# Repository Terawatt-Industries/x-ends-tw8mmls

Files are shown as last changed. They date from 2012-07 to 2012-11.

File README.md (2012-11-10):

#RepRap X-Ends for Terawatt Industries Leadscrew/Nut and LM8UU Bearings or Acetal Bushings
-----------------------------------------------------------------------------------------

This is a modified version of the popular prusa/mendelmax x-ends for use with acetal bushings from SDP and Terawatt Industries leadscrew/nut combination. It's based on the 1.1 x-end version at thingiverse.com/thing:21122. The only modifications are to allow for a flanged leadscrew nut and acetal bushings instead of LM8UUs.

If building from SCAD sources, note the assembly module's 'mode' parameter.  All prior modes from the original 1.1 are supported.

#Part Assembly Instructions
If you're not familiar with the x-axis of a reprap, you can learn more at reprap.org/wiki/Mendel_X-axis.

Assembly instructions for this part are like other x-ends, of which there are many variations. Refer to the excellent instrutions posted at reprap.org/wiki/LongboatPrusa#Instructions_11, note the variations in this part, and you should have enough to complete assembly. Let us know if you have questions!

There are two basic changes:
1) Substitutes a 8mm Terawatt Industries leadscrew for oft-used cheap drill rod. Uses a flanged nut that's bolted through with two bolts.
2) Uses acetal bushings with 17.5mm OD for the z-axis smooth-rod, typically 8mm. For example, the bushings at sdp-si.com/eStore/Direct.asp?GroupID=469

Note: The "repaired" STL file(s) corrects manifold mesh errors in the original source. All raw SCAD, STL, etc. are in the ZIP.

#Building STL from SCAD Source
An ANT script is provided for automated openscad compilation of source files in this project.  You must have ANT installed to use this build script.  ANT is based on Java and runs on Windows and Linux platforms.  The ANT build script provided with this project is a work-in-progress but it's actively used and maintained.

##Configuring ANT
The build.xml in the project depends on the Flaka ANT add-on.  To install Flaka in your environment, enter the following from a command line interface (unix):
cp [path-to-this-project]/tools/build/ant-flaka-1.02.02.jar [path-to-ANT-installation]/lib

In other words, Flaka installs like any other ANT add-on.  If you have trouble installing the library, or don't know where ANT is installed, try typing "ant -diagnostics" from a command line.

##ANT Targets
To list the targets provided by this build.xml enter "ant -p" from a command line interface.

##Building A Single Part Using ANT
To build the SCAD source files for the first time you must edit unix.settings.properties (or windows.settings.properties).  Set the path to the executable for openscad, for example (on OS X):
exec.path.oscad=/Applications/OpenSCAD.app/Contents/MacOS/OpenSCAD

Once you've edited unix.settings.properties run the following from a Unix or Windows command line to compile the SCAD source files:
ant

##Building Multiple Parts Using ANT
---------------------------------
Enter the following from a Unix or Windows command line to build 4 STL files.
cd [project-directory]
./tools/build/build-all-parts.sh

###Shell Parameters
To change the ZSTOP option (set to true by default), edit tools/build/ant_assembly.scad.tpl.  All other configuration 

We'll port the UNIX SH script to Windows BAT very soon - if you have one already please send it over!
=======

##Open Source Ancestors
1. [MendelMax 1.5 for LM10UU](http://www.thingiverse.com/thing:20355)
1. [X-Ends](http://www.thingiverse.com/thing:18384)

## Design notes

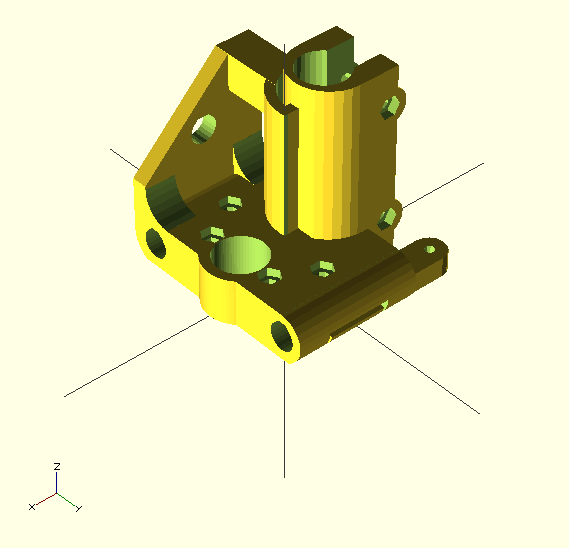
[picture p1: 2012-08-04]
img/x_ends_idler_8mmls_lm8uu.png

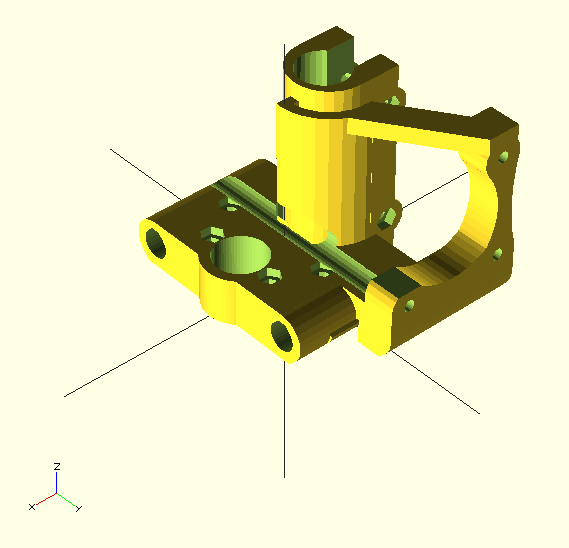
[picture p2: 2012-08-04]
img/x_ends_motormount_terawatt_lm8uu.png

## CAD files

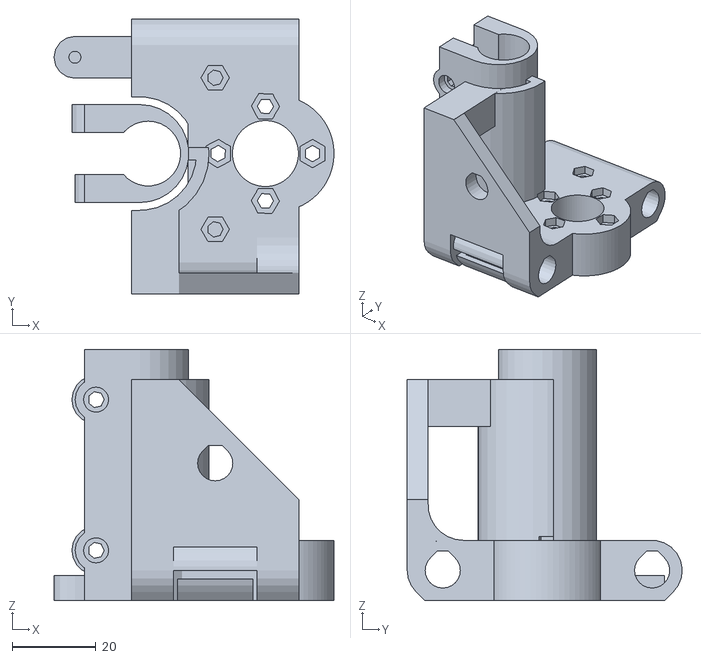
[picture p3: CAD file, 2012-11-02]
dist/x_ends_idler_8mmls_lm8uu.stl
66.9 x 65.6 x 60.0

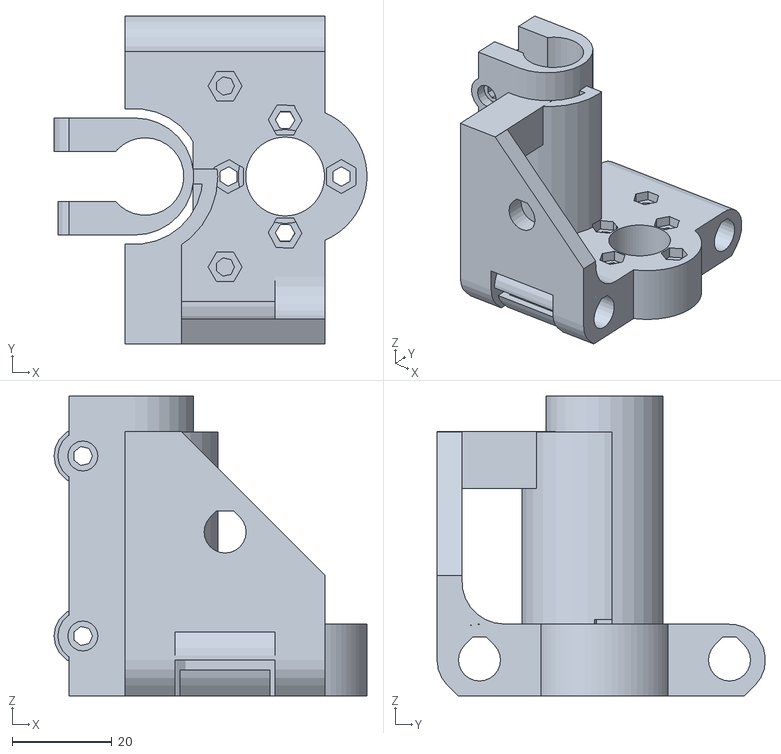
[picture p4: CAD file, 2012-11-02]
dist/x_ends_idler_8mmls_lm8uu_nozstop.stl
62.6 x 65.6 x 60.0

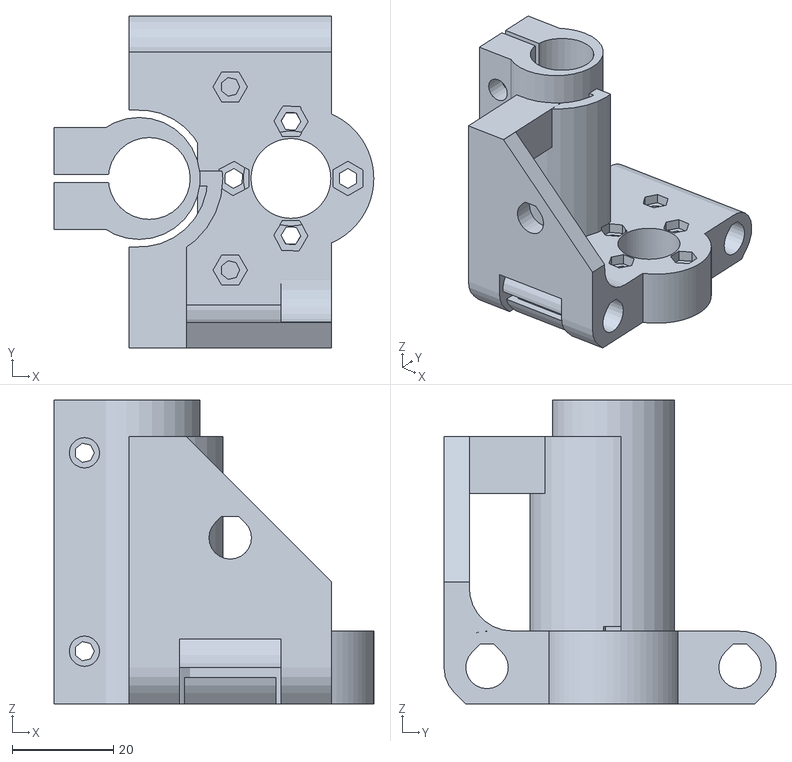
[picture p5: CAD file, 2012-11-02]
dist/x_ends_idler_8mmls_acetal_nozstop.stl
63.2 x 65.6 x 60.0

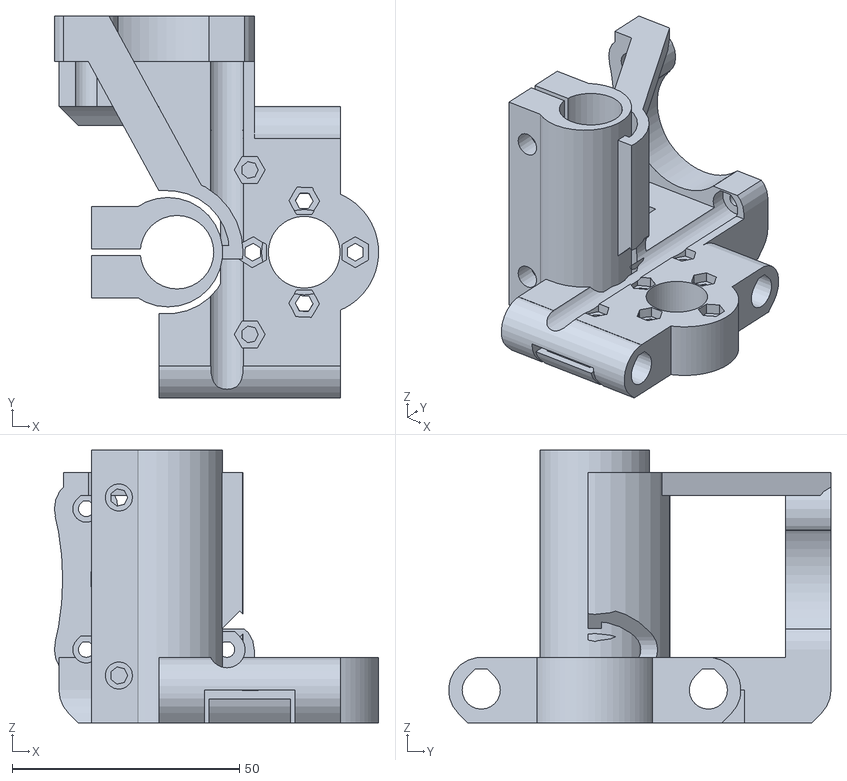
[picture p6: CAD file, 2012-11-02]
dist/x_ends_motormount_8mmls_acetal_nozstop.stl
71.4 x 84.1 x 60.0

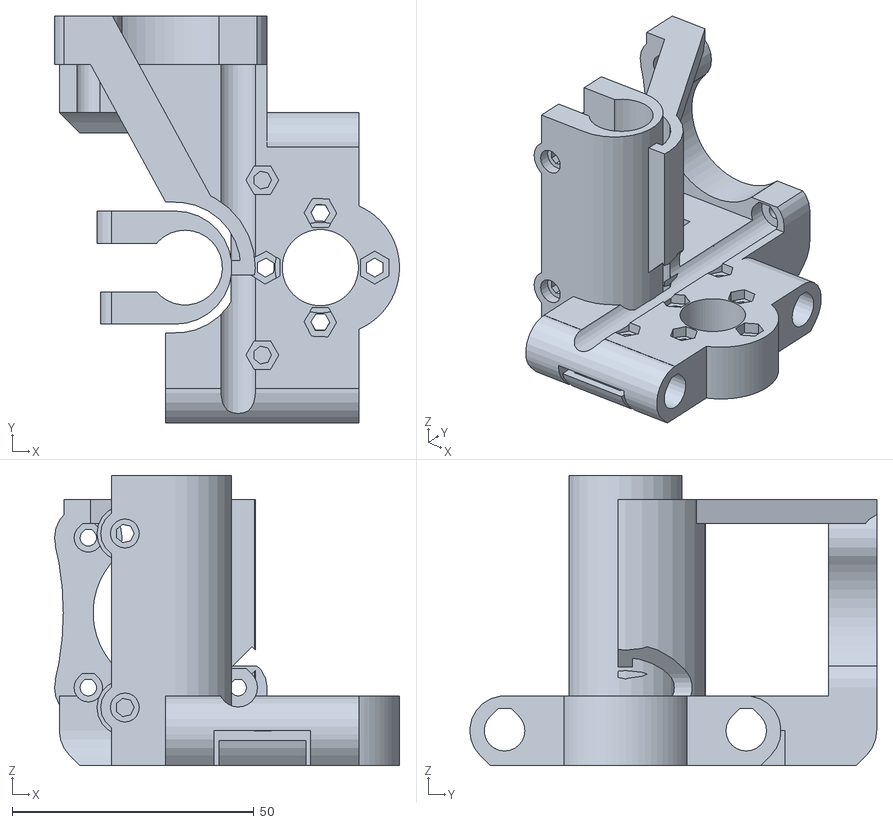
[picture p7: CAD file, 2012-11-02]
dist/x_ends_motormount_8mmls_lm8uu_nozstop.stl
71.4 x 84.1 x 60.0

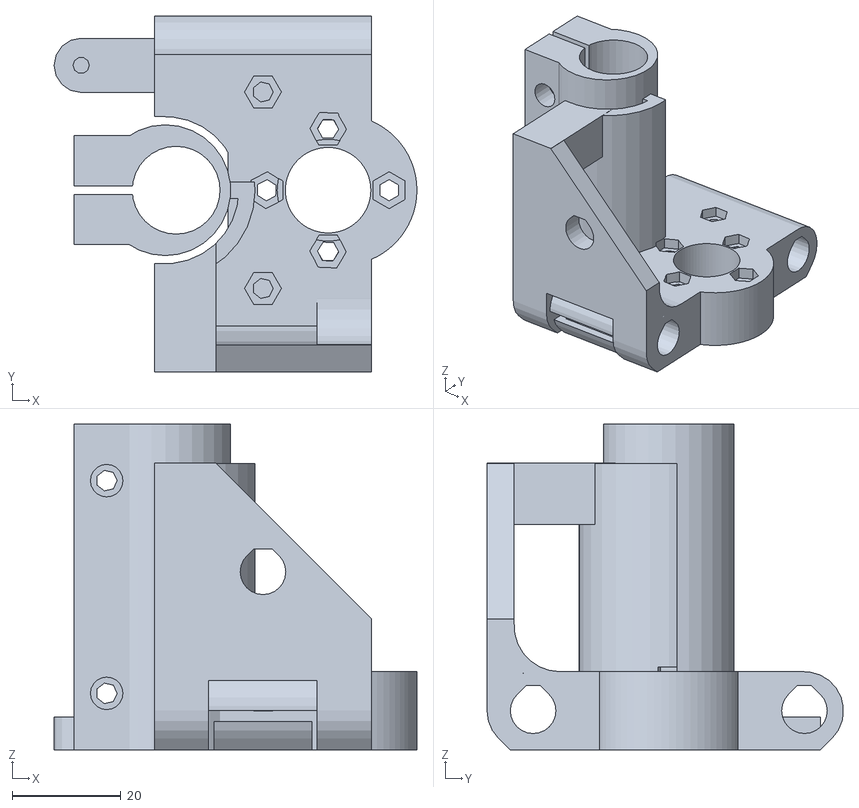
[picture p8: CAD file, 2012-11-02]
dist/x_ends_idler_8mmls_acetal.stl
66.9 x 65.6 x 60.0

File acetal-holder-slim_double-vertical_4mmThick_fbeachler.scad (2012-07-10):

// Acetal Bushing holder slim
// *********************************************
// Free Beachler
// http://www.terawattindustries.com
// http://www.thingiverse.com/fbeachler
// *********************************************
// derived from:
// http://www.thingiverse.com/thing:24574
// http://www.thingiverse.com/thing:14942

use <jonaskuehling-default.scad>

acetal_dia = 17.4;
acetal_length = 10.8;
rod_dia = 8;

//screw/nut dimensions (M3) - hexagon socket head cap screw ISO 4762, hexagon nut ISO 4032
screw_thread_dia_iso = 3;
screw_head_dia_iso = 5.5;
nut_wrench_size_iso = 5.5;


// screw/nut dimensions for use (plus clearance for fitting purpose)
clearance_dia = 0.5;
screw_thread_dia = screw_thread_dia_iso + clearance_dia;
screw_head_dia = screw_head_dia_iso + clearance_dia;
nut_wrench_size = nut_wrench_size_iso + clearance_dia;
nut_dia_perimeter = (nut_wrench_size/cos(30));
nut_dia = nut_dia_perimeter;
nut_surround_thickness = 2;

// main body dimensions
body_wall_thickness = 4;
body_width = acetal_dia + (2*body_wall_thickness);
body_height = body_width;
body_length = 60;
gap_width = 1.5;
screw_bushing_space = 1;
screw_elevation = acetal_dia + body_wall_thickness + (screw_thread_dia/2) +screw_bushing_space;
bushing_support_padding = 2;

overhang_angle = 60;
r = nut_dia_perimeter/2+nut_surround_thickness;
extra_height_varticalprint = r*sin(90-overhang_angle);

// TEST - uncomment to render in openscad:
//acetal_holder_slim_double_vertical();		



// main body
module acetal_holder_slim_double_vertical()
{
	// rotate vertical and center bearing around z-axis
	translate([0,-(acetal_dia/2+body_wall_thickness),body_length/2])
	rotate([-90,0,0])
	difference()
	{
		union()
		{	
			// body
			translate([-body_width/2 + bushing_support_padding,-body_length/2 ,body_height/2])
				cube([body_width - (2 * bushing_support_padding),body_length,(acetal_dia/2)+screw_bushing_space+(screw_thread_dia/2)+extra_height_varticalprint + 3.25]);
			translate([0,0,(acetal_dia/2)+body_wall_thickness])		
				rotate([90,0,0])
					cylinder(r=(acetal_dia/2)+body_wall_thickness, h=body_length, center=true);
	
			// gap support
			translate([-(gap_width/2)-body_wall_thickness,-(body_length/2),body_height/2])
				cube([body_wall_thickness,acetal_length,(acetal_dia/2)+screw_bushing_space+(screw_thread_dia/2)]);
			translate([gap_width/2,-(body_length/2),body_height/2])
				cube([body_wall_thickness,acetal_length,(acetal_dia/2)+screw_bushing_space+(screw_thread_dia/2)]);
			// trap nut round hole supports
			for(i=[-(body_length/2-acetal_length/2) + 5,(body_length/2-acetal_length/2) - 5])
			{
				// nut trap surround
				translate([gap_width/2 - bushing_support_padding,i,screw_elevation])
					rotate([0,90,0])
						cylinder(r=(((nut_wrench_size+nut_surround_thickness*2)/cos(30))/2), h=(body_width-gap_width)/2, $fn=20);
	
				// Screw hole surround
				translate([-gap_width/2 + bushing_support_padding,i,screw_elevation])
					rotate([0,-90,0])
						cylinder(r=(screw_head_dia/2)+nut_surround_thickness, h=(body_width-gap_width)/2, $fn=20);
			}
		}
	
		// bushing hole
		translate([0,0,acetal_dia/2+2])
			rotate([90,0,0])
				polyhole(d=acetal_dia, h=body_length+1, center=true);
	
		// top gap
		translate([-(gap_width/2),-(body_length/2)-1,body_height/2])
			cube([gap_width,body_length+2,(acetal_dia/2)+screw_bushing_space+(screw_thread_dia/2)+(nut_dia/2)+nut_surround_thickness+1]);
		// trap not holes
		for(i=[-(body_length/2-acetal_length/2) + 5,(body_length/2-acetal_length/2) - 5])
		{
			// screw hole (one all the way through)
			translate([0,i,screw_elevation])
				rotate([0,90,0])
					polyhole(d=screw_thread_dia, h=body_width+3, center=true);
		
			// nut trap
			translate([gap_width/2+body_wall_thickness,i,screw_elevation])
				rotate([0,90,0])
					cylinder(r=nut_dia/2, h=body_width/2-gap_width/2-body_wall_thickness+1,$fn=6);
		
			// screw head hole
			translate([-(gap_width)/2-body_wall_thickness,i,screw_elevation])
				rotate([0,-90,0])
					cylinder(r=screw_head_dia/2, h=body_width/2-gap_width/2-body_wall_thickness+1,$fn=20);

		}	
	}
}

/*
// Based on nophead research
module polyhole(d,h,center=false) {
    n = max(round(2 * d),3);
    rotate([0,0,180])
        cylinder(h = h, r = (d / 2) / cos (180 / n), center=center, $fn = n);
}
*/

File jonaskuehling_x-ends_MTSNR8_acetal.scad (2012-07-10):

use <jonaskuehling-default.scad>
include <acetal-holder-slim_double-vertical_4mmThick_fbeachler.scad>

// PARAMETERS
rod_dia = 8;
rod_dist = 50;		// center to center
zrod_leadscrew_dist = 30;
clearance = 0.2;		// default clearance
wall = 3;			// default wall thickness
wall_thin = 3;
xend_body_length = 40;

m3_screw_dia = 3;
m3_screw_head_dia = 5.5;
m3_screw_head_height = 3;
m3_nut_wrench_size = 5.5;
m3_nut_height = 2.4;

m8_screw_dia = 8;
m8_washer_dia = 16;
m8_washer_height = 1.5;

idler_dia = 25;		// when using pure 608 bearing without belt guide: 22mm

belt_rod_dist = 7.5;		// in y direction
belt_elevation = 6.5;		// in z direction, space between rod top and belt bottom;
						// = distance between upper side of rods and upper platform of x-carriage (with belt clamps)
belt_height = 2.6;		// belt thickness..

xmotor_y_offset = 45;
idler_y_offset = rod_dist/2+rod_dia/2+belt_rod_dist - 2*m8_washer_height;

// belt range = rod_dist/2+rod_dia/2+belt_rod_dist - nema17 shaft socket = 36.5 - 43 = 6.5mm

leadscrew_dia = 8;
leadscrew_nut_wrench_size = 13+0.2;		// plus some extra clearance
leadscrew_nut_height = 6.8;
anti_backlash_spring_space = 25;

leadscrew_dia_misumi = 8;
leadscrew_nut_wrench_size_misumi = 15+0.35;		// plus some extra clearance
leadscrew_nut_height_misumi = 20;

nema17_width = 43;
nema17_hole_dist = 31;
nema17_center_dia = 25;

layer_height = 0.25;

xend_body_x_offset = 3;
motor_mount_x_offset = -2;


// CALCULATIONS
xend_body_height = rod_dia+2*clearance+2*wall;
xend_body_width = rod_dist+rod_dia+2*wall;
leadscrew_nuttrap_height = 2*leadscrew_nut_height+wall+anti_backlash_spring_space;
leadscrew_nuttrap_height_misumi = leadscrew_nut_height_misumi + wall+13;
bearing_support_height = leadscrew_nuttrap_height;
idler_elevation = xend_body_height/2+rod_dia/2+belt_elevation+belt_height+idler_dia/2;


// RENDER
// "idler=false" for motor-x-end, "idler=true" for idler-x-end

assembly(idler=false, misumi=false, zstop=true);

// -------------------------------------------------

module rod_mount(idler=true){
	difference(){
		// block for rods
		translate([0,(rod_dist/2+rod_dia/2+wall)/2,0])
			cube([xend_body_length,rod_dist/2+xend_body_height/2,xend_body_height],center=true);
	
		// round corners horizontal
		translate([xend_body_length/2,rod_dist/2+xend_body_height/2,xend_body_height/2])
			rotate([180,90,0])
				roundcorner(xend_body_height/2,xend_body_length);
		translate([xend_body_length/2,rod_dist/2+xend_body_height/2,-xend_body_height/2])
			rotate([0,0,180]) 
				roundcorner_tear(xend_body_height/2,xend_body_length);
	
		// rod hole
		if (idler)
			translate([wall,rod_dist/2,0]) teardropcentering(rod_dia/2+clearance,xend_body_length);
		else
			translate([0,rod_dist/2,0]) teardropcentering(rod_dia/2+clearance,xend_body_length+2);
	
		// rod clamp
		translate([0,body_width/2+1,0])
		difference(){
			translate([0,(rod_dist/2+rod_dia/2+wall+1)/2,-(rod_dia/2+wall+1)/2])
				cube([xend_body_length-20,rod_dist/2+rod_dia/2+wall+1,rod_dia/2+wall+1],center=true);
			translate([0,(rod_dist/2+rod_dia/2+wall+1)/2,-(rod_dia/2+wall+1)/2-2])
				cube([xend_body_length-20-2,rod_dist/2+rod_dia/2+wall+1+2,rod_dia/2+wall+1],center=true);
		}
		translate([0,rod_dist/2,-0.1]) teardropcentering_half(rod_dia/2+clearance+1,xend_body_length-20-2-4,bottom=1);
		

		// clamp screw + nut trap + screw-head-trap
		translate([0,rod_dist/2-rod_dia/2-m3_screw_dia/2-2*clearance-1,0])
			polyhole(m3_screw_dia+2*clearance,xend_body_height+1);
		translate([0,rod_dist/2-rod_dia/2-m3_screw_dia/2-2*clearance-1,xend_body_height/2-m3_nut_height/2+0.5])
			nut_trap(m3_nut_wrench_size,m3_nut_height+1);
	}

	// screw hole print support
	translate([0,rod_dist/2-rod_dia/2-m3_screw_dia/2-2*clearance-1,layer_height/2+(xend_body_height/2-layer_height*round((xend_body_height/2)/layer_height))])
		polyhole(m3_screw_dia+2*clearance,layer_height);
}

module zstop() {
	//cornerdiameter =  (((nut_wrench_size)/2)+clearance) / cos(180/6);
	translate([-xend_body_length/2-xend_body_x_offset,(rod_dist)/2-2,0]) {
		difference() {
			union() {
				translate([0,0,6/2])
				cube([15,10,6],center=true);
				translate([-15/2,0,6/2])
				cylinder(h=6, r=5, center=true);
			}
			translate([-15/2,0,4+m3_nut_height+layer_height+0.1])
			cylinder(h=8, r=m3_screw_dia/2, center=true, $fn=10);
			translate([-15/2,0,m3_nut_height/2-.5])
			nut_trap(m3_nut_wrench_size,m3_nut_height+1);
		}
	}
}


module bearing_holder(){
	// linear bearing holder
	translate([-zrod_leadscrew_dist/2,0,0])
		rotate([0,0,90])
			acetal_holder_slim_double_vertical();
}

module bearing_holder_spacer(){
	render()
	translate([-body_width/2-zrod_leadscrew_dist/2,0,body_length/2])
		cube([body_width,body_width+3,body_length+2], center = true);
	difference(){
		translate([-zrod_leadscrew_dist/2,0,-1])
			cylinder(r=body_width/2+1.5, h=body_length+2);
		translate([body_width/2-zrod_leadscrew_dist/2+body_width/2-0.5,0,body_length/2])
			cube([body_width,body_width+3,body_length+2], center = true);
	}
}



module leadscrew_nuttrap(){
	translate([zrod_leadscrew_dist/2,0,0])
		rotate([0,0,30]){
			translate([0,0,leadscrew_nuttrap_height/2])
				difference(){
					nut_trap(leadscrew_nut_wrench_size+2*wall,leadscrew_nuttrap_height);
					nut_trap(leadscrew_nut_wrench_size,leadscrew_nuttrap_height+2);
				}
			translate([0,0,wall/2+leadscrew_nut_height])
				difference(){
					nut_trap(leadscrew_nut_wrench_size+2*wall,wall);
					rotate([0,0,-30]) cube([leadscrew_dia+1,leadscrew_nut_wrench_size*2,wall+2],center=true);
				}
		}
}

module leadscrew_nuttrap_misumi(){
	translate([zrod_leadscrew_dist/2,0,0])
		rotate([0,0,0]){
			translate([0,0,leadscrew_nuttrap_height_misumi/2])
				difference(){
					nut_trap_misumi(leadscrew_nut_wrench_size_misumi+2*wall,leadscrew_nuttrap_height_misumi);
					nut_trap_misumi(leadscrew_nut_wrench_size_misumi,leadscrew_nuttrap_height_misumi+2);
				
					// screw hole for leadscrew nut anti-rotation screw
					for (i=[0,1])
					#translate([0,0,
						leadscrew_nuttrap_height_misumi/2-wall-3.1-0.1-1.5-i*(10.9-0.2)]) 
					rotate([90,0,0]) 
					cylinder(h=leadscrew_nut_wrench_size_misumi+2*wall+1, r=m3_screw_dia/2-0.2,$fn=6,center=true);
				}
			translate([0,0,-wall/2+leadscrew_nuttrap_height_misumi])
				difference(){
					nut_trap_misumi(leadscrew_nut_wrench_size_misumi+2*wall,wall);
					//rotate([0,0,-30]) cube([leadscrew_dia+1,leadscrew_nut_wrench_size_misumi*2,wall+2],center=true);
					translate([0,0,-wall/2+layer_height+.01])
					cylinder(h=20, r=leadscrew_dia_misumi/2+0.5);
				}
		}
}

module leadscrew_nuttrap_misumi_flange(){ 
	translate([zrod_leadscrew_dist/2,0,0])
		rotate([0,0,0]){
			translate([0,0,leadscrew_nuttrap_height_misumi/2])
				difference(){
					nut_trap_misumi(leadscrew_nut_wrench_size_misumi+wall,leadscrew_nuttrap_height_misumi);
					nut_trap_misumi(leadscrew_nut_wrench_size_misumi,leadscrew_nuttrap_height_misumi+2);
					// screw hole for leadscrew nut anti-rotation screw
					for (i=[0,1])
					translate([0,0,leadscrew_nuttrap_height_misumi/2-wall-3.1-0.1-1.5-i*(10.9-0.2)]) 
					rotate([90,0,0]) 
					cylinder(h=leadscrew_nut_wrench_size_misumi+2*wall+1, r=m3_screw_dia/2-0.2,$fn=6,center=true);
				}
			translate([0,0,-wall/2+leadscrew_nuttrap_height_misumi])
				difference(){
					nut_trap_misumi(leadscrew_nut_wrench_size_misumi+wall,wall);
					//rotate([0,0,-30]) cube([leadscrew_dia+1,leadscrew_nut_wrench_size_misumi*2,wall+2],center=true);
					translate([0,0,-wall/2+layer_height+.01])
					cylinder(h=20, r=leadscrew_dia_misumi/2+0.5);
				}
		}
}

module leadscrew_nuttrap_spacer(){
	translate([zrod_leadscrew_dist/2,0,leadscrew_nuttrap_height/2])
	rotate([0,0,30])
		nut_trap(leadscrew_nut_wrench_size+2*wall,leadscrew_nuttrap_height+2);
}

module leadscrew_nuttrap_spacer_misumi(){
	translate([zrod_leadscrew_dist/2,0,leadscrew_nuttrap_height_misumi/2])
	rotate([0,0,30])
		nut_trap_misumi(leadscrew_nut_wrench_size_misumi+2*wall,leadscrew_nuttrap_height_misumi+2);
}

module leadscrew_nuttrap_spacer_misumi_flange(){
	translate([zrod_leadscrew_dist/2,0,leadscrew_nuttrap_height_misumi/2]) {
		nut_trap_misumi(leadscrew_nut_wrench_size_misumi+wall,leadscrew_nuttrap_height_misumi+2);
	//set-screws for ls-nut
	rotate([0,0,20]) {
		translate([-leadscrew_dia_misumi, -leadscrew_dia_misumi,0])
		rotate([0,0,12.5])
			nut_trap(m3_screw_dia,m3_nut_height + 35);
		translate([leadscrew_dia_misumi,leadscrew_dia_misumi,0])
		rotate([0,0,12.5])
			nut_trap(m3_screw_dia,m3_nut_height + 35);
	}
}
}


nema17_hole1 = [nema17_hole_dist/2,nema17_hole_dist/2];
nema17_hole2 = [nema17_hole_dist/2,-nema17_hole_dist/2];
nema17_hole3 = [-nema17_hole_dist/2,nema17_hole_dist/2];
nema17_hole4 = [-nema17_hole_dist/2,-nema17_hole_dist/2];
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

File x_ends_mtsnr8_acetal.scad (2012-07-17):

use <jonaskuehling-default.scad>
include <acetal_holder_slim_double-vertical_4mmThick_fbeachler.scad>
use <lm8uu-holder-slim_double-vertical_4mmThick_jmil.scad>

// PARAMETERS
rod_dia = 8;
rod_dist = 50;		// center to center
zrod_leadscrew_dist = 30;
clearance = 0.2;		// default clearance
wall = 3;			// default wall thickness
wall_thin = 3;
xend_body_length = 40;

m3_screw_dia = 3;
m3_screw_head_dia = 5.5;
m3_screw_head_height = 3;
m3_nut_wrench_size = 5.5;
m3_nut_height = 2.4;

m8_screw_dia = 8;
m8_washer_dia = 16;
m8_washer_height = 1.5;

idler_dia = 25;		// when using pure 608 bearing without belt guide: 22mm

belt_rod_dist = 7.5;		// in y direction
belt_elevation = 6.5;		// in z direction, space between rod top and belt bottom;
						// = distance between upper side of rods and upper platform of x-carriage (with belt clamps)
belt_height = 2.6;		// belt thickness..

xmotor_y_offset = 45;
idler_y_offset = rod_dist/2+rod_dia/2+belt_rod_dist - 2*m8_washer_height;

// belt range = rod_dist/2+rod_dia/2+belt_rod_dist - nema17 shaft socket = 36.5 - 43 = 6.5mm

leadscrew_dia = 8;
leadscrew_nut_wrench_size = 13+0.2;		// plus some extra clearance
leadscrew_nut_height = 6.8;
anti_backlash_spring_space = 25;

leadscrew_dia_misumi = 8;
leadscrew_nut_wrench_size_misumi = 15+0.35;		// plus some extra clearance
leadscrew_nut_height_misumi = 20;

nema17_width = 43;
nema17_hole_dist = 31;
nema17_center_dia = 25;

layer_height = 0.25;

xend_body_x_offset = 3;
motor_mount_x_offset = -2;


// CALCULATIONS
xend_body_height = rod_dia+2*clearance+2*wall;
xend_body_width = rod_dist+rod_dia+2*wall;
leadscrew_nuttrap_height = 2*leadscrew_nut_height+wall+anti_backlash_spring_space;
leadscrew_nuttrap_height_misumi = leadscrew_nut_height_misumi + wall+13;
bearing_support_height = leadscrew_nuttrap_height;
idler_elevation = xend_body_height/2+rod_dia/2+belt_elevation+belt_height+idler_dia/2;


nema17_hole1 = [nema17_hole_dist/2,nema17_hole_dist/2];
nema17_hole2 = [nema17_hole_dist/2,-nema17_hole_dist/2];
nema17_hole3 = [-nema17_hole_dist/2,nema17_hole_dist/2];
nema17_hole4 = [-nema17_hole_dist/2,-nema17_hole_dist/2];

// RENDER
// part:  0 = idler; part = 1 for motor mount
// mode:  0 = 8mm threaded rod; 1 = misumi leadscrew 8mm; 2 = misumi leadscrew 8mm + flange nut
// bearing:  0 = Acetal bushing mounts; 1 = LM8UU bearing mounts

assembly(part = 0, mode = 2, bearing = 0, zstop=true);

// -------------------------------------------------

module rod_mount(idler=true){
	difference(){
		// block for rods
		translate([0,(rod_dist/2+rod_dia/2+wall)/2,0])
			cube([xend_body_length,rod_dist/2+xend_body_height/2,xend_body_height],center=true);
	
		// round corners horizontal
		translate([xend_body_length/2,rod_dist/2+xend_body_height/2,xend_body_height/2])
			rotate([180,90,0])
				roundcorner(xend_body_height/2,xend_body_length);
		translate([xend_body_length/2,rod_dist/2+xend_body_height/2,-xend_body_height/2])
			rotate([0,0,180]) 
				roundcorner_tear(xend_body_height/2,xend_body_length);
	
		// rod hole
		if (idler)
			translate([wall,rod_dist/2,0]) teardropcentering(rod_dia/2+clearance,xend_body_length);
		else
			translate([0,rod_dist/2,0]) teardropcentering(rod_dia/2+clearance,xend_body_length+2);
	
		// rod clamp
		translate([0,body_width/2+1,0])
		difference(){
			translate([0,(rod_dist/2+rod_dia/2+wall+1)/2,-(rod_dia/2+wall+1)/2])
				cube([xend_body_length-20,rod_dist/2+rod_dia/2+wall+1,rod_dia/2+wall+1],center=true);
			translate([0,(rod_dist/2+rod_dia/2+wall+1)/2,-(rod_dia/2+wall+1)/2-2])
				cube([xend_body_length-20-2,rod_dist/2+rod_dia/2+wall+1+2,rod_dia/2+wall+1],center=true);
		}
		translate([0,rod_dist/2,-0.1]) teardropcentering_half(rod_dia/2+clearance+1,xend_body_length-20-2-4,bottom=1);
		

		// clamp screw + nut trap + screw-head-trap
		translate([0,rod_dist/2-rod_dia/2-m3_screw_dia/2-2*clearance-1,0])
			polyhole(m3_screw_dia+2*clearance,xend_body_height+1);
		translate([0,rod_dist/2-rod_dia/2-m3_screw_dia/2-2*clearance-1,xend_body_height/2-m3_nut_height/2+0.5])
			nut_trap(m3_nut_wrench_size,m3_nut_height+1);
	}

	// screw hole print support
	translate([0,rod_dist/2-rod_dia/2-m3_screw_dia/2-2*clearance-1,layer_height/2+(xend_body_height/2-layer_height*round((xend_body_height/2)/layer_height))])
		polyhole(m3_screw_dia+2*clearance,layer_height);
}

module zstop() {
	//cornerdiameter =  (((nut_wrench_size)/2)+clearance) / cos(180/6);
	translate([-xend_body_length/2-xend_body_x_offset,(rod_dist)/2-2,0]) {
		difference() {
			union() {
				translate([0,0,6/2])
				cube([15,10,6],center=true);
				translate([-15/2,0,6/2])
				cylinder(h=6, r=5, center=true);
			}
			translate([-15/2,0,4+m3_nut_height+layer_height+0.1])
			cylinder(h=8, r=m3_screw_dia/2, center=true, $fn=10);
			translate([-15/2,0,m3_nut_height/2-.5])
			nut_trap(m3_nut_wrench_size,m3_nut_height+1);
		}
	}
}

module bearing_holder(bearing) {
	// linear bearing holder
	translate([-zrod_leadscrew_dist/2,0,0])
		rotate([0,0,90])
			if (bearing != 1) {
				acetal_holder_slim_double_vertical();
			} else {
				lm8uu_holder_slim_double_vertical();
			}
}

module bearing_holder_spacer(bearing) {
	render()
	translate([-body_width/2-zrod_leadscrew_dist/2, 0, body_length/2])
		cube([body_width,body_width+3,body_length+2], center = true);
	difference(){
		translate([-zrod_leadscrew_dist/2, 0, -1])
			cylinder(r=body_width/2+1.5, h=body_length+2);
		translate([body_width/2-zrod_leadscrew_dist/2+body_width/2-0.5, 0, body_length/2])
			cube([body_width, body_width+3, body_length+2], center = true);
	}
}

module bearing_holder_support(part, bearing) {
	if (part != 0) {
		// motor mount
		translate([(body_width/2+1.5+wall/2)/2-zrod_leadscrew_dist/2,0,(nema17_hole_dist+(m3_screw_head_dia+2*clearance)/2+xend_body_height+m3_screw_dia/2+clearance+5)/2])
		cube([body_width/2+1.5+wall/2,wall,nema17_hole_dist+(m3_screw_head_dia + 2*clearance)/2 + xend_body_height + m3_screw_dia/2 + clearance + 5],center=true);
	} else {
		// idler mount
		translate([(body_width/2+1.5+wall/2)/2-zrod_leadscrew_dist/2,0,(xend_body_length/2+idler_elevation)/2])
		cube([body_width/2+1.5+wall/2,wall,xend_body_length/2+idler_elevation],center=true);
	}
}

module leadscrew_nuttrap(){
	translate([zrod_leadscrew_dist/2,0,0])
		rotate([0,0,30]){
			translate([0,0,leadscrew_nuttrap_height/2])
				difference(){
					nut_trap(leadscrew_nut_wrench_size+2*wall,leadscrew_nuttrap_height);
					nut_trap(leadscrew_nut_wrench_size,leadscrew_nuttrap_height+2);
				}
			translate([0,0,wall/2+leadscrew_nut_height])
				difference(){
					nut_trap(leadscrew_nut_wrench_size+2*wall,wall);
					rotate([0,0,-30]) cube([leadscrew_dia+1,leadscrew_nut_wrench_size*2,wall+2],center=true);
				}
		}
}

module leadscrew_nuttrap_misumi(){
	translate([zrod_leadscrew_dist/2,0,0])
		rotate([0,0,0]){
			translate([0,0,leadscrew_nuttrap_height_misumi/2])
				difference(){
					nut_trap_misumi(leadscrew_nut_wrench_size_misumi+2*wall,leadscrew_nuttrap_height_misumi);
					nut_trap_misumi(leadscrew_nut_wrench_size_misumi,leadscrew_nuttrap_height_misumi+2);
				
					// screw hole for leadscrew nut anti-rotation screw
					for (i=[0,1])
					#translate([0,0,
						leadscrew_nuttrap_height_misumi/2-wall-3.1-0.1-1.5-i*(10.9-0.2)]) 
					rotate([90,0,0]) 
					cylinder(h=leadscrew_nut_wrench_size_misumi+2*wall+1, r=m3_screw_dia/2-0.2,$fn=6,center=true);
				}
			translate([0,0,-wall/2+leadscrew_nuttrap_height_misumi])
				difference(){
					nut_trap_misumi(leadscrew_nut_wrench_size_misumi+2*wall,wall);
					//rotate([0,0,-30]) cube([leadscrew_dia+1,leadscrew_nut_wrench_size_misumi*2,wall+2],center=true);
					translate([0,0,-wall/2+layer_height+.01])
					cylinder(h=20, r=leadscrew_dia_misumi/2+0.5);
				}
		}
}

module leadscrew_nuttrap_misumi_flange(){ 
	translate([zrod_leadscrew_dist/2,0,0])
			translate([0,0,xend_body_height/2])
				difference(){
					nut_trap_misumi(leadscrew_nut_wrench_size_misumi+2*wall,xend_body_height);
					nut_trap_misumi(leadscrew_nut_wrench_size_misumi,leadscrew_nuttrap_height_misumi+2);
				translate([0, -leadscrew_dia_misumi - wall - 0.25, xend_body_height / 2 - 1]) {
				nut_trap(m3_nut_wrench_size,m3_nut_height + 1);
				nut_trap(m3_screw_dia,m3_nut_height + 35); }
				translate([0, leadscrew_dia_misumi + wall + 0.25, xend_body_height / 2 - 1]) {
				nut_trap(m3_nut_wrench_size,m3_nut_height + 1);
				nut_trap(m3_screw_dia,m3_nut_height + 35); }
				}
}

module leadscrew_nuttrap_spacer(){
	translate([zrod_leadscrew_dist/2,0,leadscrew_nuttrap_height/2])
	rotate([0,0,30])
		nut_trap(leadscrew_nut_wrench_size+2*wall,leadscrew_nuttrap_height+2);
}

module leadscrew_nuttrap_spacer_misumi(){
	translate([zrod_leadscrew_dist/2,0,leadscrew_nuttrap_height_misumi/2])
	rotate([0,0,30])
		nut_trap_misumi(leadscrew_nut_wrench_size_misumi+2*wall,leadscrew_nuttrap_height_misumi+2);
}
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

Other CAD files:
dist/x_ends_motormount_8mmls_acetal.stl
dist/x_ends_idler_misumi_acetal_nozstop.stl
dist/x_ends_idler_misumi_lm8uu.stl
dist/x_ends_idler_misumi_lm8uu_nozstop.stl
dist/x_ends_idler_misumi_acetal.stl
src/lm8uu-holder-slim_double-vertical_4mmThick_jmil.scad
src/acetal_holder_slim_double-vertical_4mmThick_fbeachler.scad
src/jonaskuehling-default.scad
src/x_ends_terawatt_acetal.scad

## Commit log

2012-07-10 first commit. /dist contains files published on Thingiverse on 07/08/2012;
    [acetal-holder-slim_double-vertical_4mmThick_fbeachler.scad, jonaskuehling-default.scad, jonaskuehling_x-ends_MTSNR8_acetal (repaired).stl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]
2012-07-10 filename cleanup; added zip, stl, and png to dist folder; this is Rev.2 -- rev.1 was printed and tested; rev.1 had a housing above the flange that was needless and cracked on me - it's gone from this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
    [acetal_holder_slim_double-vertical_4mmThick_fbeachler.scad, jonaskuehling_x-ends_MTSNR8_acetal (repaired).stl, jonaskuehling_x-ends_MTSNR8_acetal.stl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]
2012-07-17 reinstated LM8UU support from @JMil and parametrized assembly for two bearing holder types;
    [lm8uu-holder-slim_double-vertical_4mmThick_jmil.scad, x_ends_idler_mtsnr8_acetal.stl, x_ends_motormount_mtsnr8_acetal.stl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]
2012-07-21 renamed project and files;
    [x_ends_idler_misumi_acetal.stl, x_ends_idler_misumi_lm8uu.stl, x_ends_misumi_acetal.scad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]
2012-08-04 fixed smooth rod clamp support;
    [x_ends_idler_misumi_acetal.stl, x_ends_idler_misumi_lm8uu.stl, x_ends_misumi_acetal.scad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]
2012-08-04 ANT build working for compile and package targets; README updated; TARs and TGZs added;
    [acetal_holder_slim_double-vertical_4mmThick_fbeachler.scad, jonaskuehling-default.scad, lm8uu-holder-slim_double-vertical_4mmThick_jmil.scad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]
2012-08-05 fixed broken clamp support; added release candidate ANT build script;
    [x_ends_idler_misumi_acetal.stl, x_ends_idler_misumi_lm8uu.stl, x_ends_misumi_acetal.stl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]
2012-08-05 added build profiles to ANT build; created assembly template for auto-generation by ANT; added 'zip-dist-files' ANT target; ANT build tested and working for 4 parts supported by this project's SCAD;
    [x_ends_idler_misumi_lm8uu.stl, x_ends_motormount_misumi_acetal.stl, x_ends_motormount_misumi_lm8uu.stl]
2012-08-20 added profile for no z-stop part sets and added part sets to /dist;
    [x_ends_idler_misumi_acetal_nozstop.stl, x_ends_idler_misumi_lm8uu.stl, x_ends_idler_misumi_lm8uu_nozstop.stl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]
2012-08-24 hacked in 2 more set screws for leadscrew nut - they should be looped but aren't; added param for distance between leadscrew nut set screws;
    [x_ends_idler_misumi_acetal.stl, x_ends_idler_misumi_acetal_nozstop.stl, x_ends_idler_misumi_lm8uu.stl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]
2012-10-19 more fs cleanup;
    [x_ends_misumi_acetal.scad, x_ends_motormount_misumi_acetal.stl, x_ends_motormount_misumi_acetal_nozstop.stl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]
2012-11-02 cleanup for gh-pages publication;
    [x_ends_idler_8mmls_acetal.stl, x_ends_idler_8mmls_acetal_nozstop.stl, x_ends_idler_8mmls_lm8uu.stl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]
2012-11-03 more file cleanup;
    [x_ends_motormount_terawatt_acetal.stl, x_ends_motormount_terawatt_acetal_nozstop.stl, x_ends_motormount_terawatt_lm8uu.stl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]
